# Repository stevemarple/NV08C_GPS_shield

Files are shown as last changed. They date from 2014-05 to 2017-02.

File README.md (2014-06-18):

# NV08C_GPS_shield

Arduino shield supporting the NV08C-CSM GNSS (GPS/GLONASS/Galileo)
receiver module.

## License

Unless indicated otherwise hardware is released under the Creative
Commons Attribution-ShareAlike 3.0 Unported (CC BY-SA 3.0)
http://creativecommons.org/licenses/by-sa/3.0/

Unless indicated otherwise software is released under the GNU Lesser
General Public License, version 2.1.
http://www.gnu.org/licenses/lgpl-2.1.html

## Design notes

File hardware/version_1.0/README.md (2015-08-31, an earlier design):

# NV08C GPS shield v1.0

## Build instructions

The Gerber files are intended to use with 1.2mm thickness PCB in order
to obtain the correct 50 ohm impedance for the antenna track.

The PCB footprints have been chosen to enable soldering by hand rather
than requiring a reflow oven. The build order below should mean all
parts are accessible for soldering.

  1. NV08C module.
  2. 74LVC1T45 logic level translators.
  3. U.FL connector (if using).
  4. Surface mount resistors.
  5. Surface mount capacitors.
  6. Battery holder.
  7. Jumpers.
  8. Stacking headers.
  9. MCP1702 voltage regulator (3.3V, if using).
  10. SMA connector.

## Power supply

The 3.3V supply for the PCB can be derived from the main 5V supply by
using an onboard voltage regulator. In this case fit C1 (1u), C2 (1u)
and IC1 (MCP1702-3.3). A shunt should be fitted to JP1 to select the
`VREG` option. 

If preferred the PCB can be powered from the 3.3V supply; fit a shunt
to JP1 to select the `3V3` option. C1, C2 and IC1 can be omitted. On a
standard Arduino or Arduino Mega2560 board the 3.3V supply is limited
to a maximum current draw of 50mA which is not enough for the NV08C
module.

## Battery backup

To enable battery backup of the NV08C memory contents and to maintain
the current time fit a CR2032 lithium cell to the battery holder. The
board can be safely used without a backup battery; a pair of Schottky
diodes ensure power is always provided when the 3.3V supply is on.

## Active and passive antenna options

Different active and passive antenna options are possible depending on
which components are fitted. 

### Active antenna, 2.85V supply.

To use the internal 2.85V supply fit a zero ohm resistor (0R) in place of C12. Omit L1, C13 and JP6.

### External or no power supply

Fit C12 (22p), C13 (22p) and L1 (47n). The antenna supply voltage is
selected by JP6 (V_ANT). Depending on how a shunt is fitted either a
3.3V or 5V supply is provided to the active antenna. Omit the shunt if
using a passive antenna.

## PPS output

The PPS output can be connected to digital inputs 6 or 7 by fitting a
shunt to JP8. The shunt can be omitted if the PPS output is not
required.

## NV08C reset

A hardware reset of the NV08C is possible by fitting a shunt to
JP4. In this case A0 should be configured as an output and must be
high for normal operation of the NV08C module.

## Selection of Arduino and NV08C UARTs

The PCB enables the Arduino Serial and Serial1 UARTs to be connected
to the NV08C UART1 or UART2. UART1 and UART1 can be used
simultaneously but do not connect Serial and Serial1 to the same NV08C
UART, it will short the Serial and Serial1 TX lines together.

The diagrams below indicate the jumper position with a `=` marked between the jumper pins (`o`). "JPx" indicates the
position of the silkscreen label.

**JP1, 3V3 supply**

Source of the board's 3V3 power supply, which can be derived either form the Arduino's 3V3 supply or regulated from the Arduino's 5V supply by on onboard MCP1703-3.3 voltate regulator. Warning: JP1 is immediately adjecent to JP6.

  3V3 derived from on-board regulator:

    o=o o  JP1

  3V3 from Arduino's 3V3 supply:

    o o=o  JP1

**JP2, ISP link**

Use 3 jumpers to link digital pins 11, 12, and 13 to the ISP header. Fit jumpers only on Arduino boards where digital pin 11 is !MOSI, 12 is !MISO, and 13 is SCK. Do not fit the jumpers when using an Arduino Mega.

  Link SPI bus to ISP header:

      JP2   
     o = o
     o = o
     o = o

**JP3, ISP VCC**

Select voltage supply connected to the ISP header. On the standard Atmel ISP header the VCC pin indicates the voltage level used for signalling. On the Arduino the ISP header is normally connected to 5V, even for boards with 3V3 output levels.

  ISP header VCC connected to 5V:
  
    JP3  o=o o

  ISP header VCC connected to IOREF:
  
    JP3  o o=o

**JP4, GPS reset**

Fit jumper to use `A0` digital pin to control the GPS !RESET input. If no jumper is fitted then to reset the NV08C-CSM the power must be cycled or a serial command sent.

**JP5**

  Serial connected to UART1:

     JP5
    o o o
    o o o
    o=o o
    o=o o

  Serial1 connected to UART1:

     JP5
    o o o
    o o o
    o o=o
    o o=o

  Serial connected to UART2:

     JP5
    o=o o
    o=o o
    o o o
    o o o

  Serial1 connected to UART2:

     JP5
    o o=o
    o o=o
    o o o
    o o o

**JP6, GPS antenna supply voltage**

Select the supply voltage for an active GPS antenna, or omit the jumper for a passive antenna. The jumper block should not be fitted if the internal 2.85V supply is to be used.

**JP7, config**

Start-up Configuration option for the NV08C-CSM GPS module. From left to right the poistions are for GPIO3-GPIO7. GPIO3-5 are pulled up to 3V3 when a jumper is fitted, GPIO6 and GPIO7 are pulled to GND when the jumper is fitted. See datasheet for more information.

**JP8, pulse-per-second**

Fit a jumper to connect the pulse-per-second (PPS) output to digital pin 6 or 7.

  PPS connected to digital pin 7:
 
     JP8
    o=o o
  
  PPS connected to digital pin 6:
  
     JP8
    o o=o

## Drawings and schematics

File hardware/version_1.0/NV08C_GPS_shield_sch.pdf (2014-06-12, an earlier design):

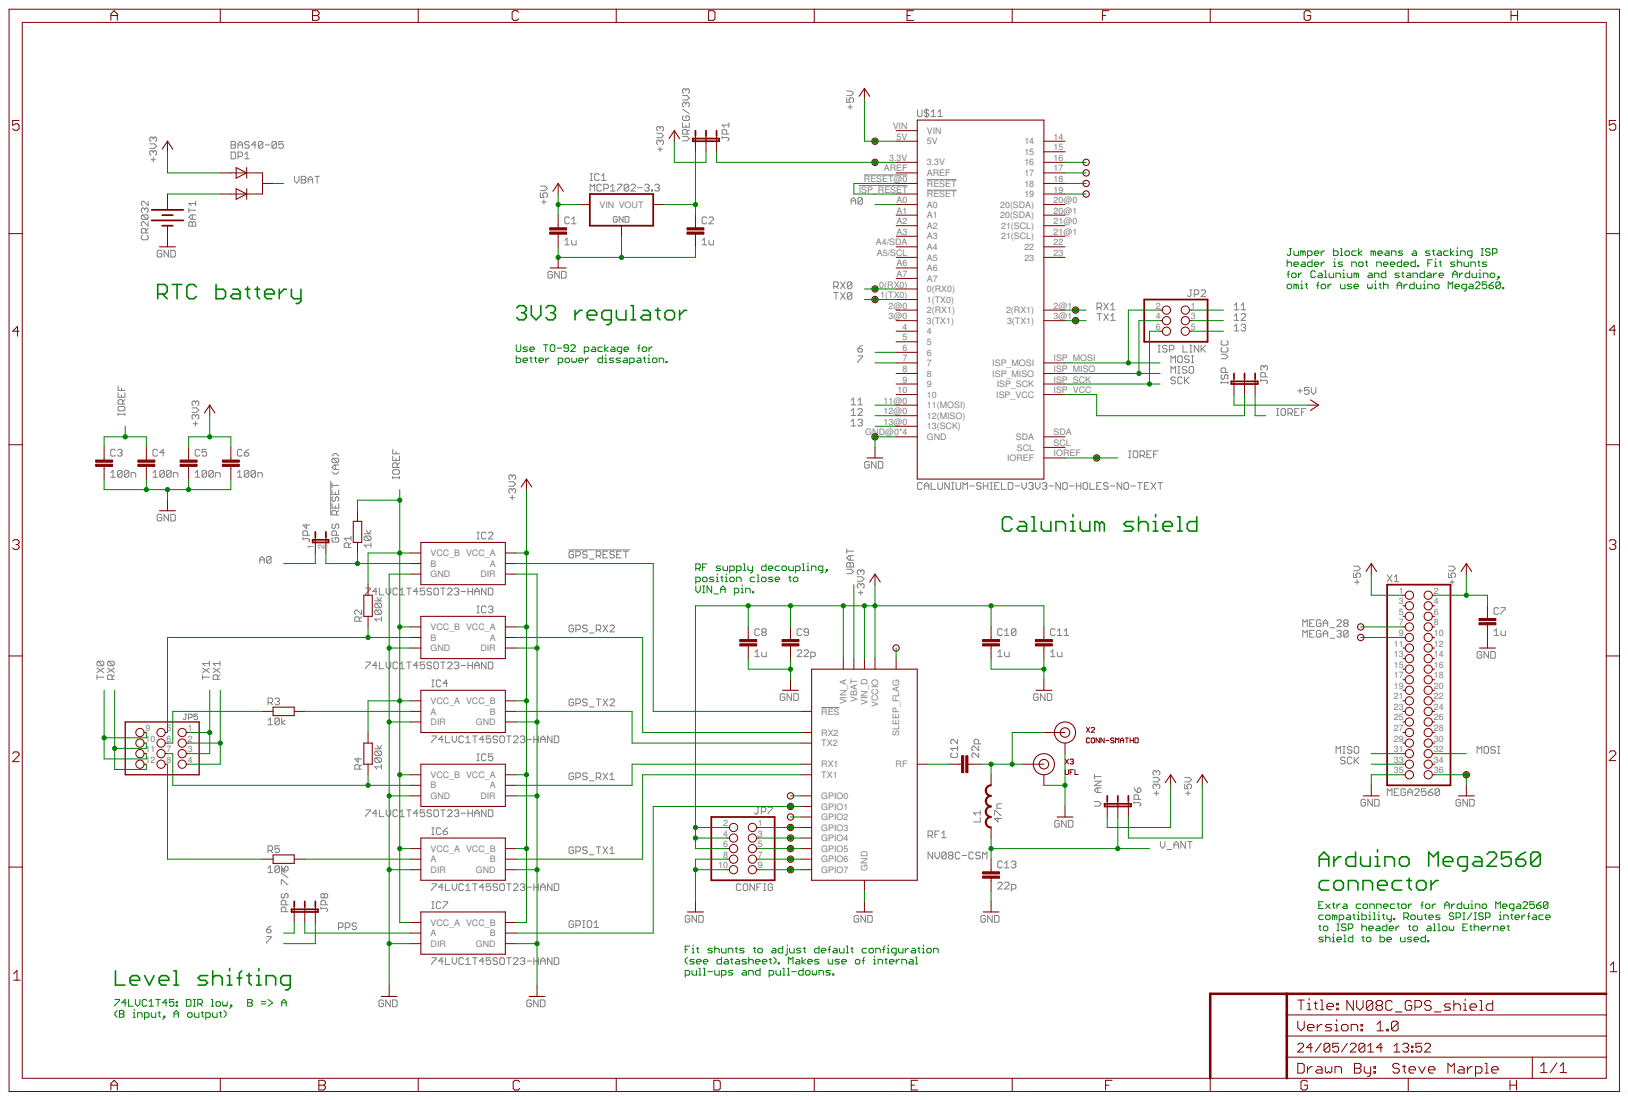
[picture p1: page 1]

VIN_A VBAT VIN_D VCCIO SLEEP_FLAG RES RX2 TX2 RX1 TX1 GPIO0 GPIO1 GPIO2 GPIO3 GPIO4 GPIO5 GPIO6 GPIO7 RF GND 5V 5V RESET RESET@0 A0 A0 A1 A1 A2 A2 A3 A3 A4 A4/SDA A5 A5/SCL A6 A6 A7 A7 1(TX0) 1(TX0) 2(RX1) 2@0 3(TX1) 3@0 4 4 5 5 6 6 7 7 8 8 9 9 10 10 16 16 17 17 18 18 11(MOSI) 11@0 12(MISO) 12@0 13(SCK) 13@0 15 15 14 14 GND GND@0*4 3.3V 3.3V AREF AREF 21(SCL) 21@0 20(SDA) 20@0 19 19 VIN VIN 0(RX0) 0(RX0) 22 22 23 23 RESET ISP_RESET ISP_SCK ISP_SCK ISP_MISO ISP_MISO ISP_MOSI ISP_MOSI 2(RX1) 2@1 3(TX1) 3@1 20(SDA) 20@1 21(SCL) 21@1 SDA SDA SCL SCL IOREF IOREF ISP_VCC ISP_VCC VIN VOUT 1234 5678 9101112 A B GND VCC_A VCC_B DIR B A GND VCC_B VCC_A DIR A B GND VCC_A VCC_B DIR B A GND VCC_B VCC_A DIR B A GND VCC_B VCC_A DIR A B GND VCC_A VCC_B DIR 2 1 4 3 6 5 2 1 4 3 6 5 8 7 10 9 12 1 2 3 4 5 6 7 8 9 10 11 12 13 14 15 16 17 18 19 20 21 22 23 24 25 26 27 28 29 30 31 32 33 34 35 36

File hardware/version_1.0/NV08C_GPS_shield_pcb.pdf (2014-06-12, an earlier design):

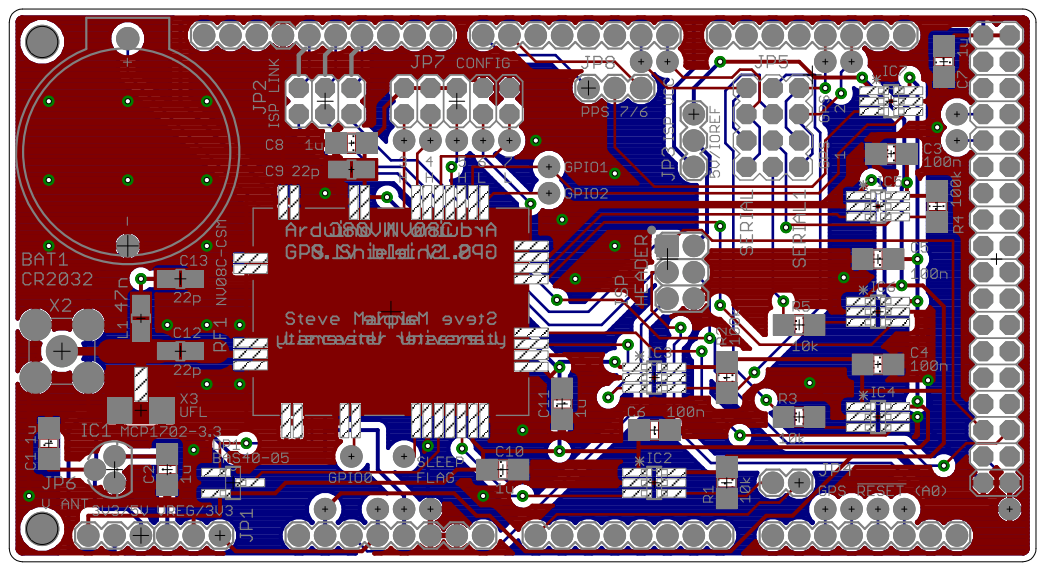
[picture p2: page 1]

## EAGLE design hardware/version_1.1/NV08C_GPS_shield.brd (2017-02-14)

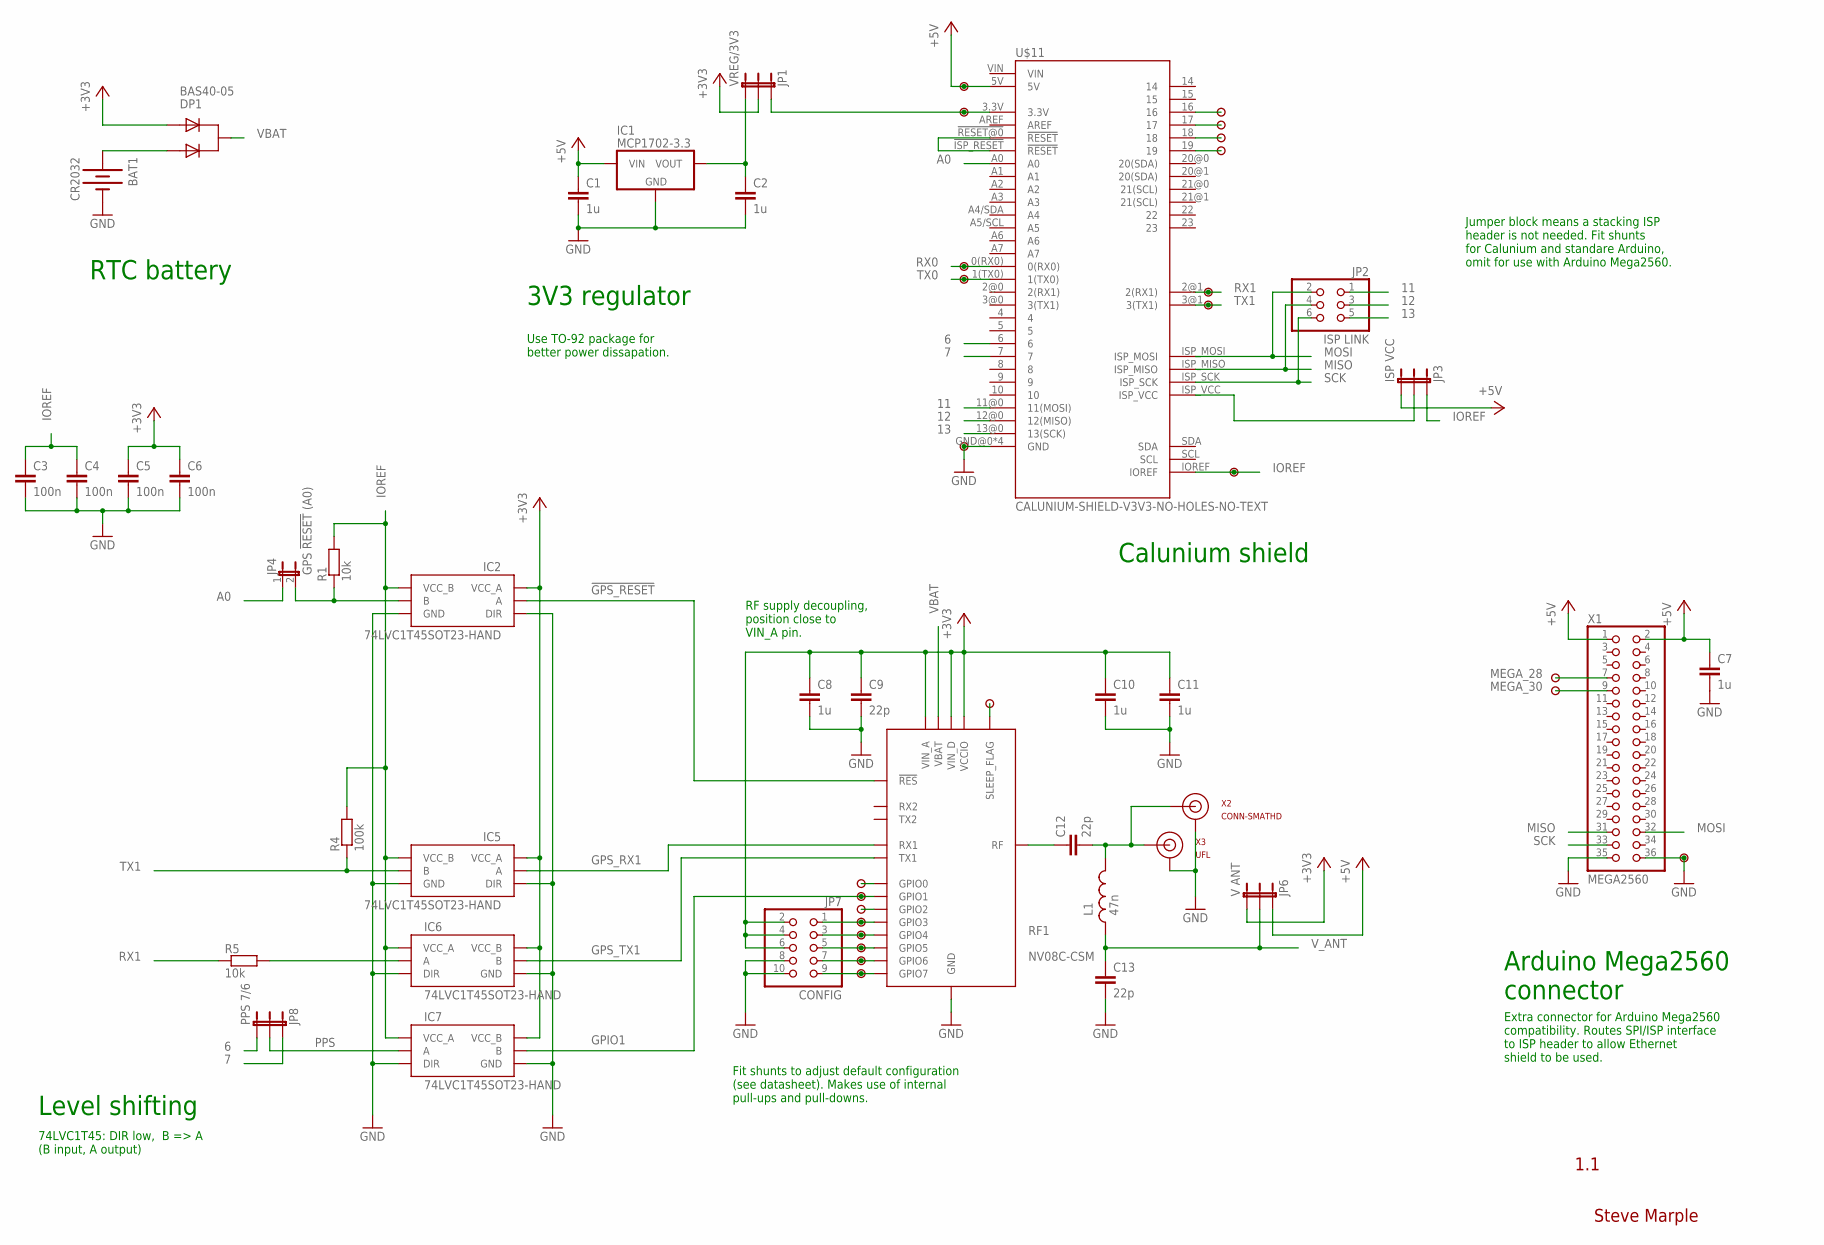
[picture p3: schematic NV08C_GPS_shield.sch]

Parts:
BAT1: CR2032; BATTCOM_20MM_PTH
C1, C2, C7, C8, C10, C11: 1u; 1206-HAND
C3, C4, C5, C6: 100n; 1206-HAND
C9, C12, C13: 22p; 0805-HAND
DP1: BAS40-05; SOT23-3-HAND
IC1: MCP1702-3.3; TO-92
IC2, IC5, IC6, IC7: 74LVC1T45SOT23-HAND; SOT23-6-HAND
JP1: VREG/3V3; 1X03
JP2: ISP LINK; 2X03
JP3: ISP VCC; 1X03
JP4: GPS !RESET! (A0); 1X02
JP6: V ANT; 1X03
JP7: CONFIG; 2X05
JP8: PPS 7/6; 1X03
L1: 47n; 0805-HAND
R1, R5: 10k; 1206-HAND
R4: 100k; 1206-HAND
RF1: NV08C-CSM; NVC08C-CSM-HAND
U$1, U$2, U$3, U$4, U$5, U$6, U$7, U$8, U$9, U$10, U$12, U$13, U$14, U$15, U$16, U$17, U$18, U$19, U$21, U$22, U$23, U$24, U$25: PAD
U$11: CALUNIUM-SHIELD-V3V3-NO-HOLES-NO-TEXT; CALUNIUM-SHIELD-NO-OUTLINE-NO-HOLES-NO-TEXT-V3
U$20: ?; PAD
X1: MEGA2560; 2X18
X2: CONN-SMATHD; SMA-THD
X3: UFL; CONN-UFL-HAND-SOLDERING

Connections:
3V3_SHIELD: JP1.1, U$2.1, U$11.3.3V
6: JP8.3, U$11.6
7: JP8.1, U$11.7
11: JP2.1, U$11.11@0 (11(MOSI))
12: JP2.3, U$11.12@0 (12(MISO))
13: JP2.5, U$11.13@0 (13(SCK))
!GPS_RESET: IC2.3 (A), RF1.P$25 (!RES)
!RESET: U$11.!ISP_RESET (!RESET), U$11.!RESET@0 (!RESET)
+3V3: C5.1, C6.1, C8.1, C9.1, C10.1, C11.1, DP1.2 (A2), IC2.1 (VCC_A), IC5.1 (VCC_A), IC6.6 (VCC_B), IC7.6 (VCC_B), JP1.2, JP6.3, JP7.2, JP7.4, JP7.6, RF1.P$8 (VIN_A), RF1.P$26 (VIN_D), RF1.P$28 (VCCIO)
+5V: C1.1, C7.1, IC1.2 (VIN), JP3.3, JP6.1, U$1.1, U$11.5V, X1.1, X1.2
A0: JP4.1, U$11.A0
GND: BAT1.2 (-), C1.2, C2.2, C3.2, C4.2, C5.2, C6.2, C7.2, C8.2, C9.2, C10.2, C11.2, C13.2, IC1.1 (GND), IC2.2 (GND), IC2.5 (DIR), IC5.2 (GND), IC5.5 (DIR), IC6.2 (GND), IC6.5 (DIR), IC7.2 (GND), IC7.5 (DIR), JP7.8, JP7.10, RF1.P$3 (GND), RF1.P$9 (GND), RF1.P$10 (GND), RF1.P$11 (GND), RF1.P$12 (GND), RF1.P$13 (GND), RF1.P$14 (GND), RF1.P$16 (GND), RF1.P$17 (GND), RF1.P$18 (GND), RF1.P$19 (GND), RF1.P$22 (GND), RF1.P$24 (GND), RF1.P$27 (GND), RF1.P$29 (GND), RF1.P$34 (GND), U$11.GND@0 (GND), U$11.GND@1 (GND), U$11.GND@2 (GND), U$11.GND@3 (GND), U$12.1, U$17.1, X1.35, X1.36, X2.GND@0 (GND), X2.GND@1 (GND), X2.GND@2 (GND), X2.GND@3 (GND), X3.GND@0 (GND), X3.GND@1 (GND)
GPIO0: RF1.P$20 (GPIO0), U$18.1
GPIO1: IC7.4 (B), RF1.P$2 (GPIO1), U$19.1
GPIO2: RF1.P$1 (GPIO2), U$20.1
GPIO3: JP7.1, RF1.P$6 (GPIO3), U$21.1
GPIO4: JP7.3, RF1.P$7 (GPIO4), U$22.1
GPIO5: JP7.5, RF1.P$4 (GPIO5), U$23.1
GPIO6: JP7.7, RF1.P$35 (GPIO6), U$24.1
GPIO7: JP7.9, RF1.P$5 (GPIO7), U$25.1
GPS_RX1: IC5.3 (A), RF1.P$33 (RX1)
GPS_TX1: IC6.4 (B), RF1.P$32 (TX1)
IOREF: C3.1, C4.1, IC2.6 (VCC_B), IC5.6 (VCC_B), IC6.1 (VCC_A), IC7.1 (VCC_A), JP3.1, R1.2, R4.2, U$11.IOREF, U$13.1
ISP_VCC: JP3.2, U$11.ISP_VCC
MEGA_28: U$14.1, X1.7
MEGA_30: U$15.1, X1.9
MISO: JP2.4, U$11.ISP_MISO, X1.31
MOSI: JP2.2, U$11.ISP_MOSI, X1.32
unnamed: C2.1, IC1.3 (VOUT), JP1.3
unnamed: U$6.1, U$11.19
unnamed: C12.2, L1.2, X2.SIG (SIGNAL), X3.SIGNAL
unnamed: IC6.3 (A), R5.2
unnamed: U$5.1, U$11.18
unnamed: C12.1, RF1.P$15 (RF)
unnamed: IC2.4 (B), JP4.2, R1.1
unnamed: U$4.1, U$11.17
unnamed: U$3.1, U$11.16
PPS: IC7.3 (A), JP8.2
RX0: U$7.1, U$11.0(RX0)
RX1: R5.1, U$9.1, U$11.2@1 (2(RX1))
SCK: JP2.6, U$11.ISP_SCK, X1.33
SLEEP_FLAG: RF1.P$21 (SLEEP_FLAG), U$16.1
TX0: U$8.1, U$11.1(TX0)
TX1: IC5.4 (B), R4.1, U$10.1, U$11.3@1 (3(TX1))
VBAT: DP1.3 (C), RF1.P$23 (VBAT)
VBATT: BAT1.1 (+), DP1.1 (A1)
V_ANT: C13.1, JP6.2, L1.1

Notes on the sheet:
1.1
Steve Marple
Level shifting
3V3 regulator
RTC battery
74LVC1T45: DIR low, B => A (B input, A output)
RF supply decoupling, position close to VIN_A pin.
Use TO-92 package for better power dissapation.
Calunium shield
Arduino Mega2560 connector
Extra connector for Arduino Mega2560 compatibility. Routes SPI/ISP interface to ISP header to allow Ethernet shield to be used.
Jumper block means a stacking ISP header is not needed. Fit shunts for Calunium and standare Arduino, omit for use with Arduino Mega2560.
Fit shunts to adjust default configuration (see datasheet). Makes use of internal pull-ups and pull-downs.

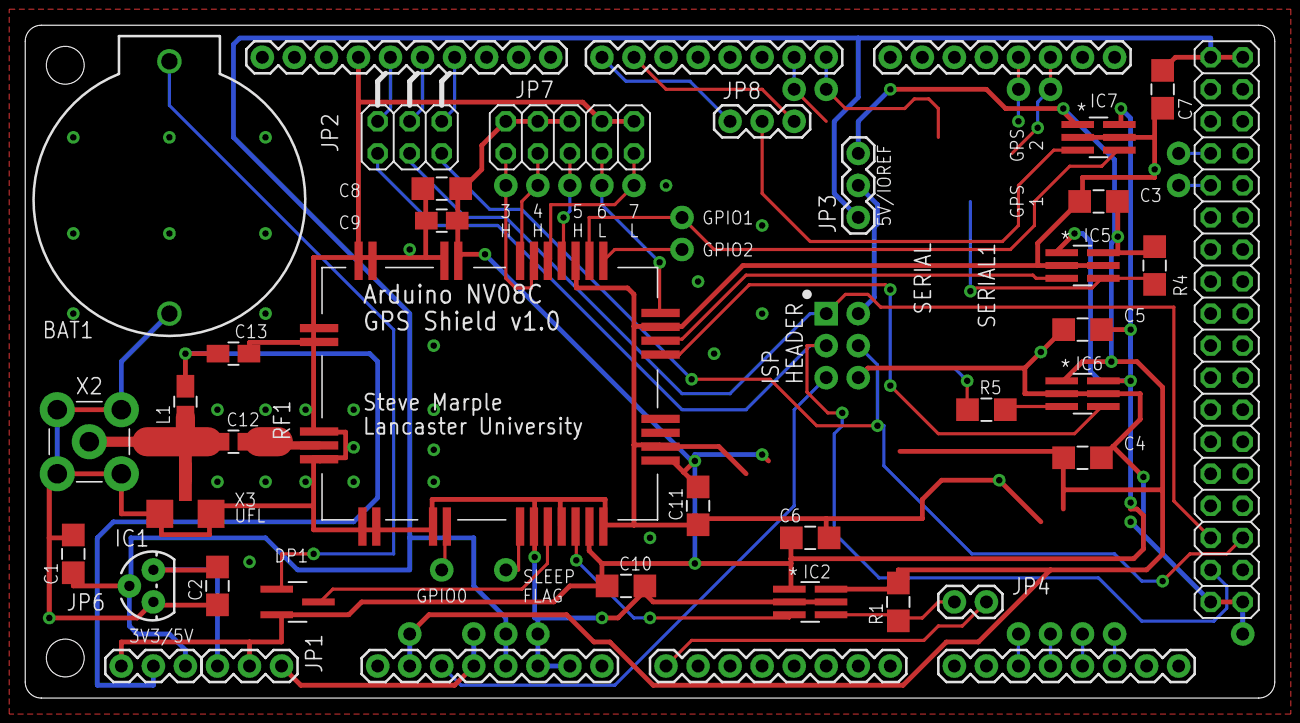
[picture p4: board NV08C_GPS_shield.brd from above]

Board: 2 copper layers, 99.1 x 53.3 mm, 60 parts (0 on the bottom side), 47 nets.

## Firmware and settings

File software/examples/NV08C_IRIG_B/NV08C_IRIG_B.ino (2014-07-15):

#include <avr/wdt.h>

#include <TinyGPS.h>
#include <AsyncDelay.h>
#include <Wire.h>
#include <RTCx.h>

// GPS parsing object
TinyGPS nmea;

// Refer to streams logically
Stream& console = Serial;
Stream& gps = Serial1;

bool debug = false;
AsyncDelay debugTimeout;
unsigned long maxDebugTime_ms = 300000; // 5 minutes


/*
 * IRIG-B format is:
 *  1 '*' 
 *  2 step number ('0' to '7')
 *  3 units second digit (ASCII decimal) 
 *  4 tens second digit 
 *  5 units minute digit 
 *  6 tens minute digit 
 *  7 units hour digit 
 *  8 tens hour digit 
 *  9 units digit day-of-year 
 * 10 tens digit day-of-year 
 * 11 hundreds digit day-of-year 
 * 12 tens year digit 
 * 13 units year digit 
 * 14 time quality 
 * 15 CR 
 * 16 LF 
 */

const int bufferLen = 20; 
char bufferA[bufferLen] = "";
char bufferB[bufferLen] = "";
char *nextTime = bufferA;
char *thisTime = bufferB;
bool thisFixValid = false;
bool nextFixValid = false;

RTCx::time_t nextPPS = 0;

volatile bool ppsTriggered = false;

// Toggle an output pin state at every step. This will be useful for
// checking the timing and delays.
bool squareWaveOut = LOW;
uint8_t squareWavePin = 8;

// The original IRIG-B unit read a character from the serial stream to
// configure the number of steps per second. Configure in the firmware
// instead - it's more useful to keep the serial data input available
// for talking to the bootloader. stepsPerSecond should divide exactly
// into 1000 otherwise the steps will not be evenly distributed
// through the second.
const uint8_t stepsPerSecond = 8;
uint8_t stepCounter = 0;
AsyncDelay stepDelay;

void resetGPS(bool cold = true);

void ppsHandler(void)
{
  ppsTriggered = true;
}


void resetGPS(bool cold)
{
  if (cold)
    gps.print("$PORST,F*20\r\n"); // Factory restart and cold start
  else
    gps.print("$PORST,W*31\r\n"); // Keep settings and warm restart
}


void formatTime(const RTCx::time_t &t, uint16_t numSat,
		char *buffer, size_t bufferLen)
{
  struct RTCx::tm tm;
  char satCode;
  
  if (numSat == TinyGPS::GPS_INVALID_SATELLITES)
    satCode = '0';
  else if (numSat < 10)
    satCode = '0' + numSat; // '0' to '9'
  else if (numSat > 35)
    satCode = 'Z'; 
  else
    satCode = ('A' + numSat - 10); // 'A' to 'Z'

  RTCx::gmtime_r(&t, &tm);

  int yy;
  if (tm.tm_year + 1928 < 2000)
    yy = 00;
  else
    yy = (tm.tm_year + 1928) % 100;
  
  int ydayp1 = tm.tm_yday + 1;
  snprintf(buffer, bufferLen,
	   "%1d%1d%1d%1d%1d%1d%1d%1d%1d%02d%c\r\n",
	   (tm.tm_sec % 10), (tm.tm_sec / 10),
	   (tm.tm_min % 10), (tm.tm_min / 10),
	   (tm.tm_hour % 10), (tm.tm_hour / 10),
	   (ydayp1 % 10), ((ydayp1 / 10) % 10), (ydayp1 / 100),
	   yy, satCode);

}


void setup(void)
{
  wdt_enable(WDTO_8S);
  
  // Set I/O as inputs with pull-ups. Leave D0 and D1 as normal INPUT
  // without pullups.
  for (uint8_t i = 2; i < NUM_DIGITAL_PINS; ++i)
    pinMode(i, INPUT_PULLUP);
  
#ifdef CALUNIUM
  pinMode(3, INPUT);
  pinMode(4, INPUT);
#else
  // Assume Arduino Mega(2560)
  pinMode(18, INPUT);
  pinMode(19, INPUT);
#endif
  Serial.begin(9600); // console
  Serial1.begin(115200); // gps

  pinMode(LED_BUILTIN, OUTPUT);
  digitalWrite(LED_BUILTIN, LOW);

  pinMode(squareWavePin, OUTPUT);
  digitalWrite(squareWavePin, LOW);
  // resetGPS();
  
  // Compatibility mode off
  // $PONME,,,1,0*58

  // Set compatibility mode on. Talker ID is set to "GP" even when
  // using GNSS, so that GPGGA is sent, not GLGGA or GNGGA.
  gps.print(",,,0,0*59\r\n");

  // Delete all messages from the list which are sent.
  gps.print("$PORZB*55\r\n");

  // Send RMC and GGA messages.
  gps.print("$PORZB,RMC,1,GGA,1*48\r\n");

#ifdef CALUNIUM
  pinMode(6, INPUT);
  attachInterrupt(2, ppsHandler, RISING);
#else
#error Please configure interrupt handler code for alternative board.
#endif
}


void loop(void)
{
  wdt_reset();
  
  if (ppsTriggered) {
    ppsTriggered = false;
    stepCounter = 0;

    // Swap buffers
    char *tmp = thisTime;
    thisTime = nextTime;
    nextTime = tmp;

    // Invalidate data in the nextTime buffer
    *nextTime = '\0';

    thisFixValid = nextFixValid;
    nextFixValid = false;
    
    squareWaveOut = HIGH;
  }

  if ((stepCounter == 0 || stepDelay.isExpired())
      && stepCounter < stepsPerSecond && *thisTime) {

    digitalWrite(squareWavePin, squareWaveOut);
    squareWaveOut = !squareWaveOut;

    // Start timer before sending serial data (might be slow)
    stepDelay.start(1000 / stepsPerSecond, AsyncDelay::MILLIS);

    if (*thisTime) {
      // Print step details to console
      console.print('*');
      console.print(stepCounter, DEC);
      console.print(thisTime);
    }

    switch (stepCounter) {
    case 0:
      // Turn LED on if have a valid fix
      digitalWrite(LED_BUILTIN, thisFixValid);

      // Generate the next time string based on current time. This
      // occurs immediately after the string for the first time step
      // has been printed, and before any NMEA processing for the
      // current time can have occurred. Thus if another value occurs
      // (eg time correction, leap seconds etc) then it will overwrite
      // this value.
      formatTime(++nextPPS, 0, nextTime, bufferLen);
      break;

    case 1:
      digitalWrite(LED_BUILTIN, !thisFixValid);
      break;
    }
	
    ++stepCounter;
  }
  
  while (!ppsTriggered && gps.available()) {
    char c = gps.read();
    if (debug) {
      console.print(c);
    }
    
    if (nmea.encode(c)) {
      // New sentence
      int16_t year;
      uint8_t month, mday, hour, minute, second, hundredths;
      unsigned long fix_age;
      nmea.crack_datetime(&year, &month, &mday,
			  &hour, &minute, &second, &hundredths, &fix_age);

      if (fix_age < 1000) {
	struct RTCx::tm tm;
	tm.tm_year = year - 1928; // Use 1928, not 1900 for extra range
	tm.tm_mon = month - 1;
	tm.tm_mday = mday;
	tm.tm_hour = hour;
	tm.tm_min = minute;
	tm.tm_sec = second;

	// Seconds since 1998, not 1970. This gives 28 years more before
	// the unix time rollover bug kicks in, ie 2038+28 = 2066.
	nextPPS = RTCx::mktime(tm) + 1;
	nextFixValid = true;
	formatTime(nextPPS, nmea.satellites(), nextTime, bufferLen);
	

	if (debug) {
	  console.println();
	  console.print("Next: ");
	  console.print(nextTime);
	}
	
      }
    }
  }

  while (!ppsTriggered && console.available()) {
    char c = console.read();
    if (c == '\n')
      gps.print("\r\n");
    else if (c == '!') {
      console.println("Reset GPS");
      resetGPS(false);
    }
    else if (c == '#') {
      debug = !debug;
      if (debug) {
	console.println("Entering debug mode");
	debugTimeout.start(maxDebugTime_ms, AsyncDelay::MILLIS);
      }
      else
	console.println("Leaving debug mode");
    }
    else if (c == 'f') {
      console.print("MCU frequency: ");
      console.println(F_CPU, DEC);
    }
    else
      gps.print(c);
  }

  // Do not stay in debug mode permanently in case the symbol to enter
  // was sent accidentally.
  if (debug && debugTimeout.isExpired()) {
    console.println("Debug mode timeout");
    debug = false;
  }
}

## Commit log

2014-05-08 Adding design files.
    [NV08C_GPS_shield.brd, NV08C_GPS_shield.sch]
2014-05-08 Changed BAS32L to BAV70.
    [NV08C_GPS_shield.brd, NV08C_GPS_shield.sch]
2014-05-18 Switching to 0805 packages for some parts.
    [NV08C_GPS_shield.brd, NV08C_GPS_shield.sch]
2014-05-18 Layout changes and some missing pin connections made.
    [NV08C_GPS_shield.brd, NV08C_GPS_shield.sch]
2014-05-18 Adding protection resistors in GPS TX lines.
    Enables the same UART to be used to access the bootloader during the boot
    sequence without damaging the level shifters or external FTDI device.
    [NV08C_GPS_shield.brd, NV08C_GPS_shield.sch]
2014-05-19 Change PPS pin used. Add decoupling for NV08C module.
    [NV08C_GPS_shield.brd, NV08C_GPS_shield.sch]
2014-05-20 Minor layout and silkscreen fixes.
    [NV08C_GPS_shield.brd, NV08C_GPS_shield.sch]
2014-05-20 Layout and silkscreen changes. Ground pour added.
    [NV08C_GPS_shield.brd, NV08C_GPS_shield.sch]
2014-05-21 Minor routing and silkscreen changes. Extra pads added.
    Adding extra pads to access unused Arduino pins for easier hacking.
    [NV08C_GPS_shield.brd, NV08C_GPS_shield.sch]
2014-05-21 Minor layout changes.
    [NV08C_GPS_shield.brd, NV08C_GPS_shield.sch]
2014-05-21 Adjusting position of NV08C GPS module and some other components.
    NV08C moved 0.1" left.
    [NV08C_GPS_shield.brd, NV08C_GPS_shield.sch]
2014-05-21 Minor changes to improve SCK routing and GND fill.
    [NV08C_GPS_shield.brd]
2014-05-21 Fixing existing comments and adding new ones.
    [NV08C_GPS_shield.sch]
2014-05-21 Adding CAM file for Iteadstudio PCB service.
    Modified version which outputs _tsilk and _bsilk layers.
2014-05-21 Adding Gerber files.
    [NV08C_GPS_shield.GBL, NV08C_GPS_shield.GBO, NV08C_GPS_shield.GBP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]
2014-05-24 Fixing text objects in drawing frame.
    [NV08C_GPS_shield.sch]
2014-05-24 Translate to (0,0). Minor silkscreen changes.
    [NV08C_GPS_shield.brd]
2014-05-24 Revised Gerber files.
    [NV08C_GPS_shield.GBL, NV08C_GPS_shield.GBO, NV08C_GPS_shield.GTL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]
2014-05-24 Adding PDFs of schematic and PCB.
2014-06-12 Creating separate hardware directory.
    [NV08C_GPS_shield.GBL, NV08C_GPS_shield.GBO, NV08C_GPS_shield.GBP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]
2014-06-18 Adding 8 second watchdog timer.
2014-06-18 Fix off-by-one error, 'Z' = 35 satellites.
    [NV08C_IRIG_B.ino]
2014-07-15 Fixing units, tens, hundreds order for time and day of year.
    [NV08C_IRIG_B.ino]
2017-02-14 Add hardware version 1.1
    [NV08C_GPS_shield.brd, NV08C_GPS_shield.sch]
